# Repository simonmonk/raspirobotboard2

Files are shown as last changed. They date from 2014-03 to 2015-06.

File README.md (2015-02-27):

Source code for use with the RaspiRobot Board V2.

**Note that if you are looking for version 1 of this board, please see:**

https://github.com/simonmonk/raspirobotboard

***Both version 1 and version 2 of the RasPiRobot Board work just fine with the new Raspberry Pi2 and the Model B+***

# Support
If you need any help with the software or board please contact linda@monkmakes.com or leave a comment on monkmakes.com

# Introduction

Version 2 of the RaspiRobot Board (RRB2) has learnt by the feedback from version 1 and it is a great improvement. 

RRBv2

The main features of version 2 are listed below. Changes from version 1 are highlighted in bold:
+ **Supplied fully assembled - no soldering**
+ Bi-directional control of two motors
+ **Variable (PWM) power control**. This allows you to both control the speed of the motors independently. 
+ **Supplies the Raspberry Pi with upto 2A using a switch mode power supply - run a fully loaded Pi and the Robot from 6 x AA batteries**
+ **Rangefinder header socket directly compatible with cheap HC-SR-04 ultrasonic range finders. Just plug them in directly**
+ **5V I2C header, pin compatible with Adafruit displays**
+ Two buffered open collector outputs
+ Two LEDs
+ Two switch inputs
+ Screw terminals for motors and battery

RRBv2

# How it Works

The diagram below shows how an RRB2 board is used. The RRB2 is powered from a battery pack that needs to be between 6 and 12V DC. Although using 4 x AA batteries can in theory provide 6V, actually the battery voltage will usually quickly fall below that, so it it better to use at least 6 x AA batteries, either rechargeable or regular heavy duty batteries. A 7.2V LiPo battery pack will also work just fine.

RRBv2

Note that you don't need a separate power supply for the Raspberry Pi. The RRB2 will provide 5V at 2A with ease to the Raspberry Pi, and motors. 

Note that 6V motor will usually work just fine at 5V.

# Installing the Python Libraries

On your Raspberry Pi, issue the following commands in a Terminal window:

```
$ wget https://github.com/simonmonk/raspirobotboard2/raw/master/python/dist/rrb2-1.1.tar.gz
$ tar -xzf rrb2-1.1.tar.gz
$ cd rrb2-1.1
$ sudo python setup.py install
```

Attach the RRB2 to your Raspberry Pi. You do not need to attach batteries, motors or anything else to the RRB2 just yet. For now you can just power it through the Pi's normal USB power connector.

Lets run some tests from the Python Console now that everything is installed. We can experiment with the RaspiRobot Board v2, even without any motors 

Open a Python console (Python2 not 3) by typing the following into a Terminal window:
`$ sudo python`

Then, within the python console, type the following, one line at a time:

```
from rrb2 import *
rr = RRB2()
rr.set_led1(1)
rr.set_led1(0)
rr.set_led2(1)
rr.set_led2(0)
rr.sw1_closed()
```

The last step should display the answer "False" because no switch is attached.

If you prefer, you can use True and False in place of 1 and 0 in the examples above.

# Connect a Battery and Motors

The quickest way to use the RRB2 as a roving robot is to buy a robot chassis such as the Magician Chassis (available from many sources) or similar low-cost robot chassis kits from eBay. These kits come as a laser cut body, a pair of gearmotors, often a battery box and nuts and bolts to fix it all together.

Here is one such chassis. The first step is to bolt this all together. Note that these are usually supplied with a 4 x AA battery box. You will need to swap this for a similar 6 x AA battery box or a 7.2V LiPo battery pack. Rechargeable batteries are a good idea when driving motors.

Chassis

Once the chassis is built, use some of the bolts suppled to fix the Raspberry Pi on the chassis and then attach the RRB2 onto the GPIO connector. Make sure its the right way arround, and that all the pins meet up with the socket.

The leads from the motors will thread up through the chassis and each pair of leads should go to one of the two screw terminals labelled L and R for (left and right). If you put the leads in the wrong way around, the direction of the motor will be opposite to that expected, so just swap them over if this happens.

Motor wiring

Next, make sure that your Raspberry Pi's USB power lead is unplugged. From now on we are going to power it from batteries.

**WARNING: Never power the Raspberry Pi from both batteries and the USB power connector. One or other, but NOT both.**

It is a good idea to leave the wheels off the robot chassis for now so that it does not unexpectedly drive itself off your table. One or both of the motors may spin as the Raspberry Pi starts up.

Wire the battery pack into the third pair of screw terminals. +V towards the outside of the board. The Raspberry Pi's power light should light up and it will start to boot. LED1 and LED2 on the RRB2 will also light up.

Having your Pi set up for WiFi will allow you to connect to it wirelessly [over SSH](http://learn.adafruit.com/adafruits-raspberry-pi-lesson-6-using-ssh/overview). So, you may want to plug in a USB WiFi dongle.

# API Reference

## General
The library implements a class called RRB2. This is only available for Python 2 and any Python programs that you write that use the libaray must be run as a super user. I.e.

`sudo python myProgram.py'

To import the library and create an instance of the class, put this at the top of your Python program.

```
from rrb2 import *
rr = RRB2()
```

If you have an older revision 1 Raspberry Pi, then you need to do this instead:

```
from rrb2 import *
rr = RRB2(revision=1)
```

The rest is pretty straightforward, there are just a load of useful methods on the class that you can use.

## LEDs

There are two LEDs built-in to the RaspiRobotBoard, called LED1 and LED2. Both of these can be turned on and off using the following methods:

To turn LED1 on just do:

`rr.set_led1(1)`

To turn it off again do:

`rr.set_led1(0)`

To control LED2 just do the same thing but using setLED2.

## Switch Inputs

The sw1_closed() and sw2_closed() functions return true if the contacts for that switch are closed. By default, the switches are open. You can test out closing the switch by shorting the two contacts with a screwdriver.

The following test program will show you the state of each of the switch contacts.

```
from rrb2 import *

rr = RRB2()

while True:
    print("SW1=" + str(rr.sw1_closed()) + " SW2=" + str(rr.sw2_closed()))
    raw_input("check again")
```

## Open Collector Outputs

The RaspiRobotBoard has two low-power open collector outputs. These can each source up to 25mA and so are suitable for driving LEDs with series resistors. They can also be used to drive transistors and other external electronics. They are buffered and therefore protect the Raspberry Pi' s processor.

To turn the Open Collector OC1 output on just do:

`rr.set_oc1(1)`

To turn it off again do: 

`rr.set_oc1(0)`

To control OC2, substitute oc2 in place of oc1 in the examples above

## Motor (High Level Interface)

There are two levels of command for controlling the motors. There is a high level interface that assumes that the motors are connected to wheels on a rover. These commands are forward, reverse, left, right and stop.

`rr.forward()`

... will start both motors running in the same direction to move the robot rover forwards. They will continue in this direction until another command is issued.

If you want to move forward for a certain amount of time, you can specify a number of seconds as an optional first argument. If you supply a second parameter between 0 and 1 this will control the speed of the motor. This is set to 0.5 as a defaut. If you want the motors to run indefinately, but also want to control the speed, then use 0 as the first patrameter.

Some examples:

```
rr.forward()       # forward half speed indefinately
rr.forward(5)      # forward for 5 seconds at half speed
rr.forward(5, 1)   # forward for 5 seconds at full speed
```

The commands left, right and reverse all work in the same way.

The stop command stops all the motors.

## Motor (Low Level Interface)

The low level interface is intended for control of the motors directly. It allows you to control the speed of each motor and its direction independently.

The method for this (set_motors) takes four arguments: the left speed, left motor direction, right spped and direction.

So to set both motors going forward at full speed, you would just use the following:

`rr.set_motors(1, 0, 1, 0)`

.. and half speed would be:

`rr.set_motors(0.5, 0, 0.5, 0)`

to send the motors both at half speed in opposite directions is:

`rr.set_motors(0.5, 1, 0.5, 0)`

## Range Finder

If you fit the RRB2 with an SR-04 ultrasonic rangefinder, then you can use the following call to measure the distance to the enarest obstacle in cm.

`rr.get_distance()`

## Hardware

The RRB2 uses the following pins:

    LEFT_GO_PIN = 17
    LEFT_DIR_PIN = 4
    RIGHT_GO_PIN = 10
    RIGHT_DIR_PIN = 25   
    SW1_PIN = 11
    SW2_PIN = 9
    LED1_PIN = 7
    LED2_PIN = 8
    OC1_PIN = 22
    OC2_PIN = 27
    OC2_PIN_R1 = 21 (rev 1) or 27 rev 2
    TRIGGER_PIN = 18
    ECHO_PIN = 23

The LEDs and OC outputs are buffered. The switch inputs are not.

You can find the EAGLE design files in the "hardware" section of tis repo.

# Using I2C Displays

The I2C socket is pin compatible with these Adafruit displays: 
+ [4 Digit 7-segment display (red)](http://www.adafruit.com/products/878)
+ [Mini 8x8 LED Matrix (red)](http://www.adafruit.com/products/870)
+ [Bi-color 8x8 LED Matrix (red)](http://www.adafruit.com/products/902)

To use these you will need to download Adafruit's Python library for the Pi from [here](http://learn.adafruit.com/matrix-7-segment-led-backpack-with-the-raspberry-pi/overview).

Make sure that you plug the display in the right way around. The socket pins are labelled on the RRB2, make sure they match up with the labels on the display. You can use male to female jumper wires if you wish to put the display further away or its too big.

# Example Projects

Have a look in the "examples" folder of this library for some examples using the RRB2.

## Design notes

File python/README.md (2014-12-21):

raspirobotboard 2
=================

Source for the RaspiRobotBoard Python library.

For full instructions for installation and use, see:

https://github.com/simonmonk/raspirobotboard2

for Version 1 (through hole kit) of the RaspiRobotBoard, see: https://github.com/simonmonk/raspirobotboard/wiki

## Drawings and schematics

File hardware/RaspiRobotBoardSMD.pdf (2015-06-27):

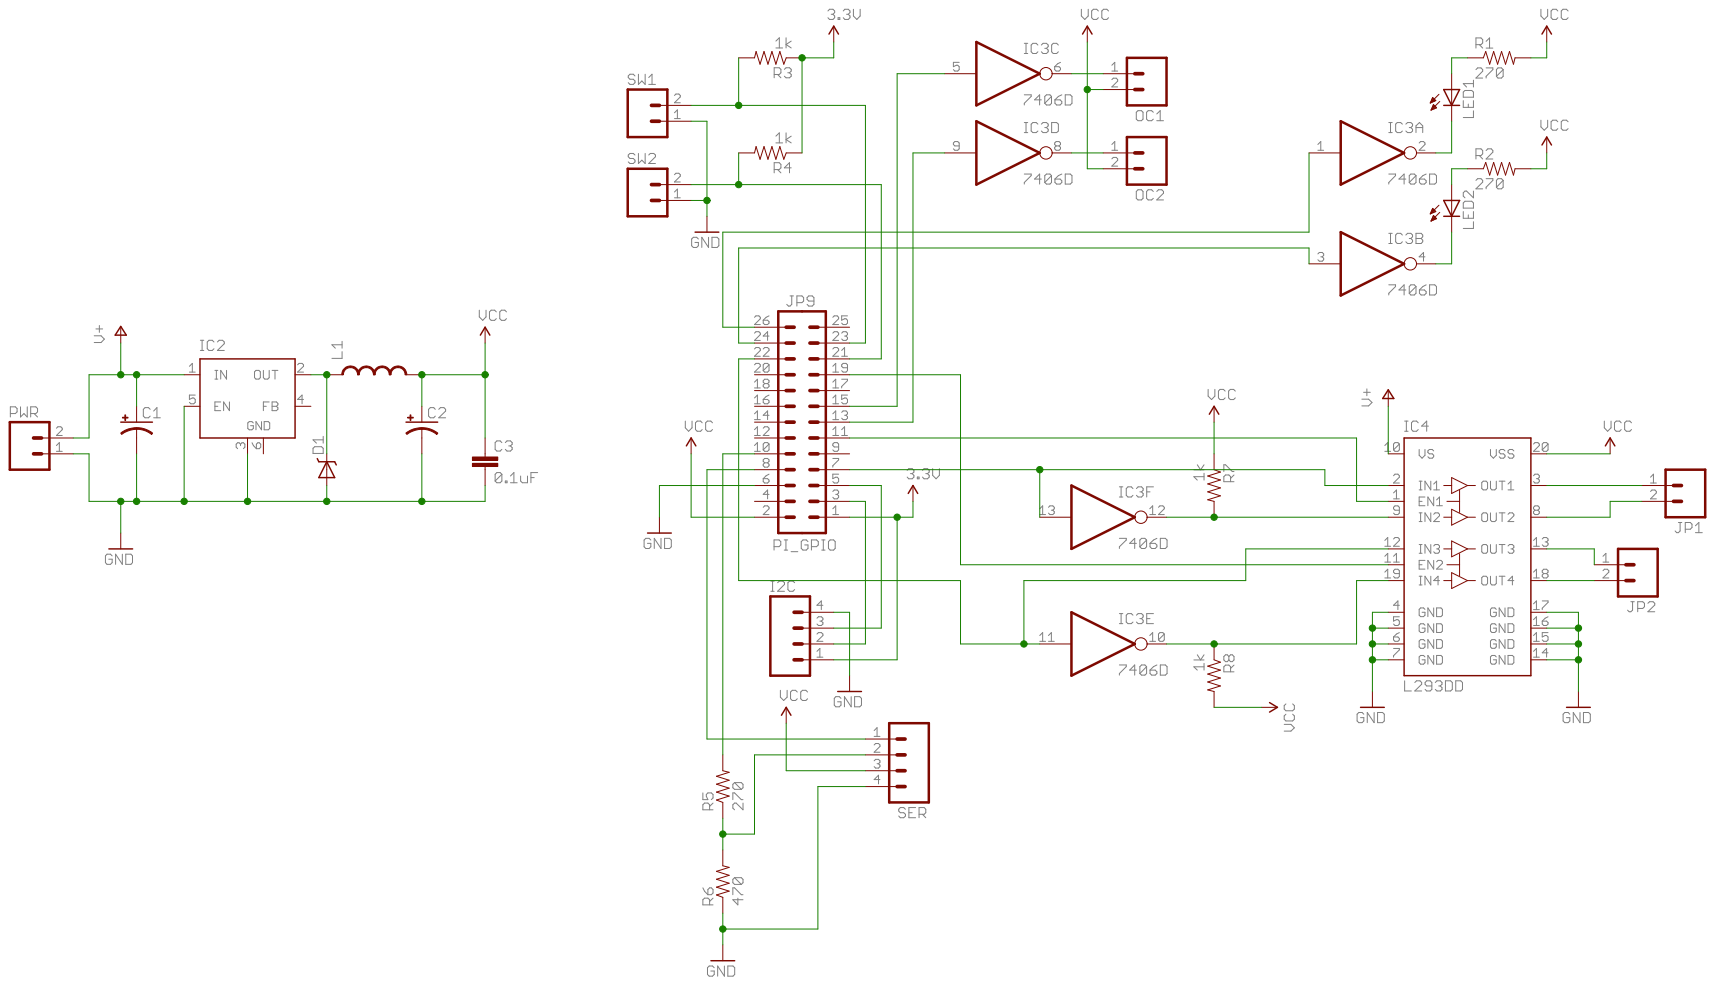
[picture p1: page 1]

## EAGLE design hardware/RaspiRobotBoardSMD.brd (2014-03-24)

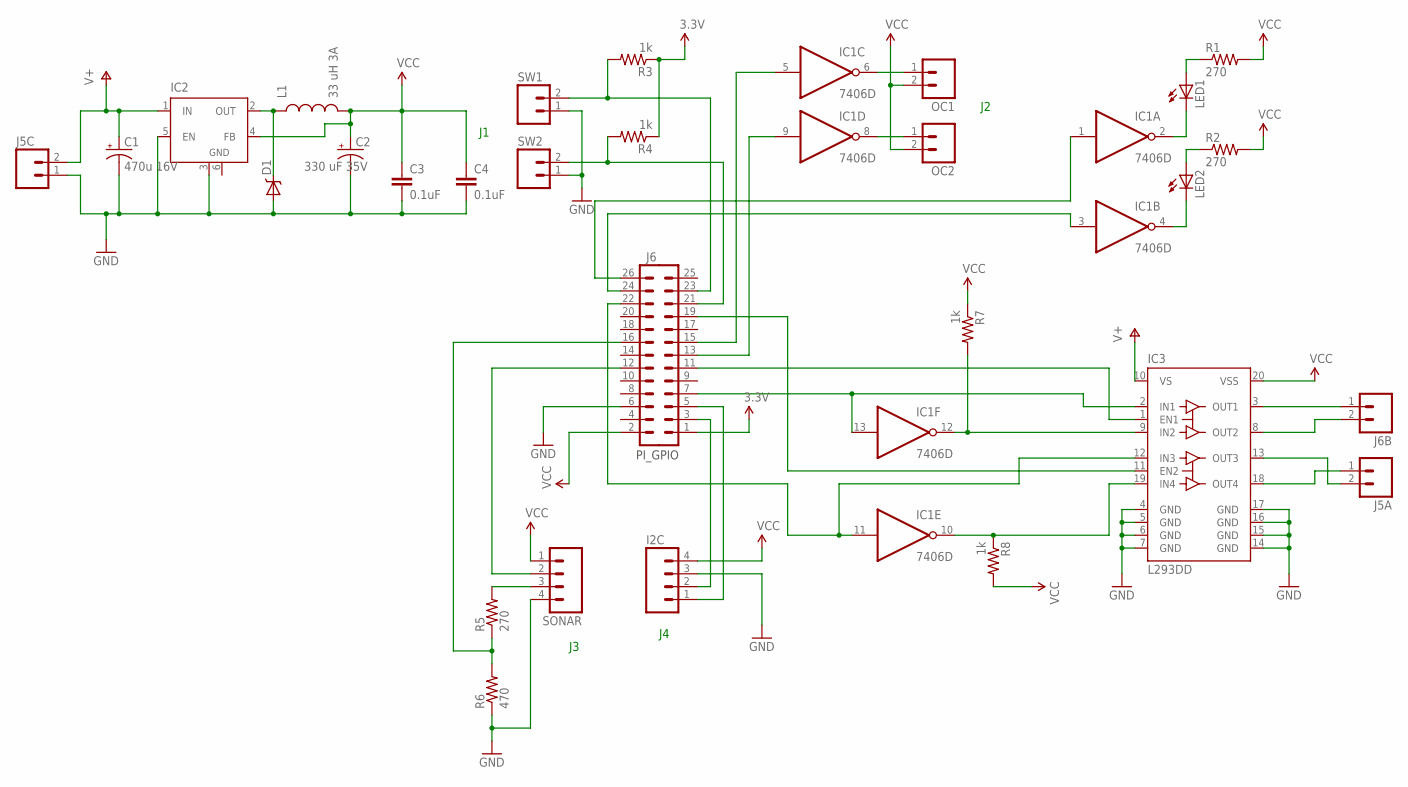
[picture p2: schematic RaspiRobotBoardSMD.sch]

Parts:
C1: 470u 16V; PANASONIC_E
C2: 330 uF 35V; PANASONIC_G
C3, C4: 0.1uF; 0805
D1: B340A; SMA-DIODE
I2C: M04PTH; 1X04
IC1: 7406D; SO14
IC2: LM2596S; TO263-5
IC3: L293DD; SO20
J5A, J5C, J6B: M023.5MM_LOCK; SCREWTERMINAL-3.5MM-2_LOCK
J6: M13X22X13; 2X13
L1: 33 uH 3A; CDRH125
LED1, LED2: LEDSMT1206; 1206
OC1, OC2: M02PTH; 1X02
R1, R2, R5: 270; 0805
R3, R4, R7, R8: 1k; 0805
R6: 470; 0805
SONAR: M04PTH; 1X04
SW1, SW2: M02PTH; 1X02

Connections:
3.3V: J6.1, R3.1, R4.1
GND: C1.-, C2.-, C3.2, C4.2, D1.A, I2C.3, IC1.7 (GND), IC2.3 (GND), IC2.5 (EN), IC2.6 (GND), IC3.4 (GND), IC3.5 (GND), IC3.6 (GND), IC3.7 (GND), IC3.14 (GND), IC3.15 (GND), IC3.16 (GND), IC3.17 (GND), J5C.1, J6.6, R6.1, SONAR.4, SW1.1, SW2.1
unnamed: D1.C, IC2.2 (OUT), L1.1
unnamed: IC3.3 (OUT1), J6B.1
unnamed: IC3.8 (OUT2), J6B.2
unnamed: IC3.18 (OUT4), J5A.1
unnamed: IC1.13 (I), IC3.2 (IN1), J6.7
unnamed: IC1.12 (O), IC3.9 (IN2), R7.2
unnamed: IC1.10 (O), IC3.19 (IN4), R8.1
unnamed: IC1.11 (I), IC3.12 (IN3), J6.22
unnamed: LED1.A, R1.1
unnamed: LED2.A, R2.1
unnamed: IC1.2 (O), LED1.C
unnamed: IC1.4 (O), LED2.C
unnamed: IC1.6 (O), OC1.1
unnamed: IC1.8 (O), OC2.1
unnamed: J6.23, R3.2, SW1.2
unnamed: J6.21, R4.2, SW2.2
unnamed: IC1.3 (I), J6.24
unnamed: J6.16, R5.1, R6.2
unnamed: J6.12, SONAR.2
unnamed: R5.2, SONAR.3
unnamed: IC1.1 (I), J6.26
unnamed: IC3.1 (EN1), J6.11
unnamed: IC3.11 (EN2), J6.19
unnamed: IC1.9 (I), J6.13
unnamed: IC1.5 (I), J6.15
unnamed: I2C.2, J6.3
unnamed: I2C.1, J6.5
unnamed: IC3.13 (OUT3), J5A.2
V+: C1.+, IC2.1 (IN), IC3.10 (VS), J5C.2
VCC: C2.+, C3.1, C4.1, I2C.4, IC1.14 (VCC), IC2.4 (FB), IC3.20 (VSS), J6.2, L1.2, OC1.2, OC2.2, R1.2, R2.2, R7.1, R8.2, SONAR.1

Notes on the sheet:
PI_GPIO

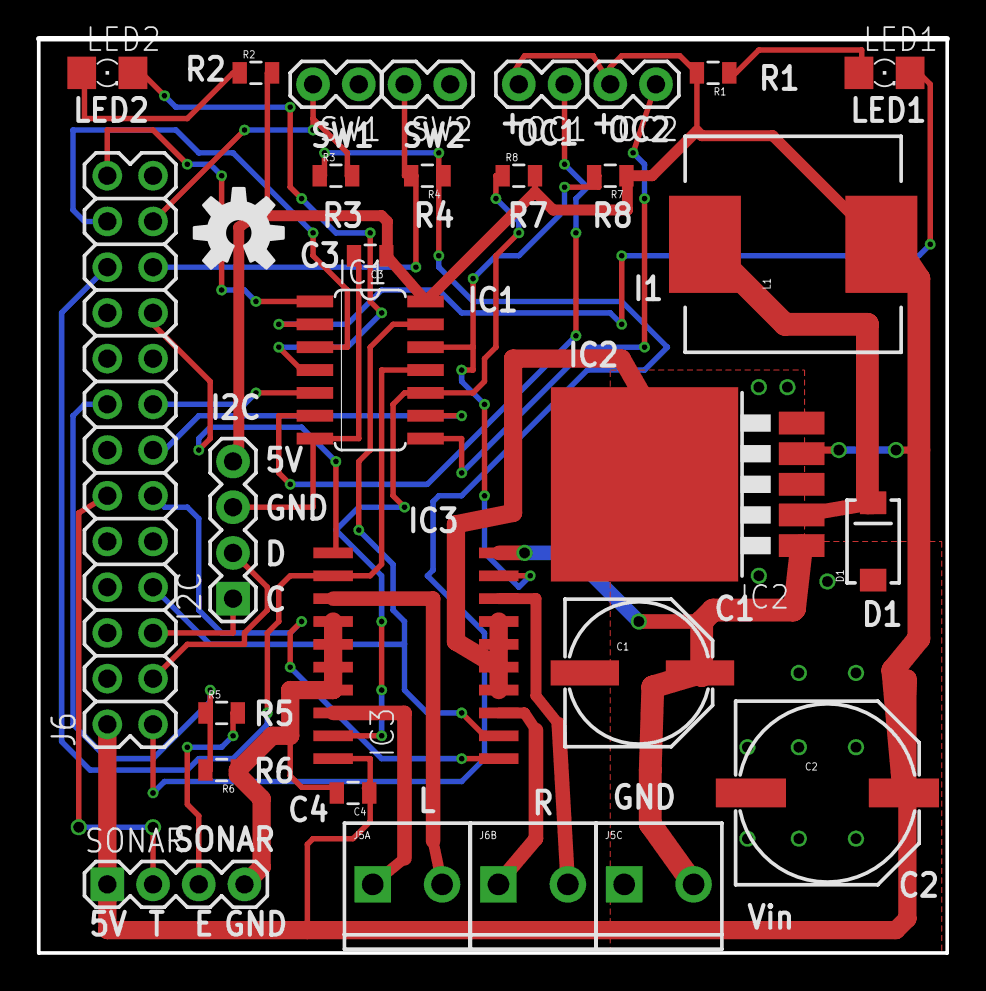
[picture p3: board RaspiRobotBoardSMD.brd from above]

Board: 2 copper layers, 50.5 x 50.8 mm, 30 parts (0 on the bottom side), 32 nets.

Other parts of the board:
U$1: OSHW-LOGO-M

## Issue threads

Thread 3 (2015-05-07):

12V 4.2A input?

HsienYu, 2015-05-07:
Hi,
I am wondering is the input voltage same as v1 (5v ~ 12`v)?

thanks!!

simonmonk, 2015-05-07:
The RRB2 will cope with up to 15V in.

However, be aware that unlike the RRB1, the RRB2 supplies 5V regulated power to the motors, rather than the input voltage.

Si.

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

--
Simon Monk. http://www.simonmonk.org

HsienYu, 2015-05-07:
Cool, thanks!
I have other question, my pi b 2 always reboot when I use rrrb2.
It often happens when I except command via ssh with wifi dongle.

simonmonk, 2015-05-07:
What battery pack are you using?

The problem is that the battery voltage will drop, when say motors start up and if the voltage drops too low it causes the Pi to restart. Using something like a 7.4V LiPo battery or 6 x AA battery pack should prevent this.

Si.

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

--
Simon Monk. http://www.simonmonk.org

--
Simon Monk. http://www.simonmonk.org

HsienYu, 2015-05-08:
I am using 6 x AA and 12v dc 4.2a adapter for testing, but with 6 xAA the reboot issue still happenes when I execute command. um... kind of wired. But thanks a lot!! I will check all the details and update soon!

HsienYu, 2015-05-09:
Hi Simon,
I did the setup with 7.4V LiPo battery, but it seem to be nothing changed.
My pi also often reboot when my motor started.

Do you know some way to avoid this kind of things happen?

Thank you very much!!

simonmonk, 2015-05-09:
What kind of motors are you using?

One trick is to put a high value capacitor say 1000uF 25V in the Vin screw terminals (longer lead of capacitor to +V).

Another trick is to start the motor at slow speed first then increase speed after say 1/10 second.

Si.

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

--
Simon Monk. http://www.simonmonk.org

HsienYu, 2015-05-10:
I am using regular 7.2 dv motor. I did try increasing speed, it's fine now.
Thank you very much and appreciate that!!

Have a good day!

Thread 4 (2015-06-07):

How to connect additional GPIO devices?

cudmore, 2015-06-07:
It is really nice that the board comes pre-soldered.

Is there any way to attach additional input/output devices to the unused GPIO pins of the raspberry? It seems all the pins on the Pi are 'capped off' because of the 'pre-soldered' connector.

Can you ship the controller with everyhting soldered except the GPIO connector? I could just solder an extra tall male to female connector (tall male running through motor controller and sticking out the top, female inserted into Pi GPIO below.

Is there some sort of 'T' connector one could put between the Pi and the motor controller? To give access to the pins.

I am always connecting junk to my Pi GPIO. To start, I would like to connect 2 servos for pan/tilt of a Rapsberry Pi Camera.

Thanks

cudmore, 2015-06-07:
i just found this tutorial where the motor board has extra tall headers. Is this how it is shipped? I am about to buy it.

https://learn.adafruit.com/controlling-motors-using-the-raspberry-pi-and-raspirobot-board-v2?view=all

ismailuddin, 2015-06-07:
The board is shipped with a tall header which you can (physically atleast) connect other pins on to it. There's table in the README file listing which pins are used by this board, so if I'm not mistaken, any pin not being used should be accessible through the header on the board for your own use..?

cudmore, 2015-06-07:
Thanks so much #ismailuddin. I will order one now and start my first robot!

Just for reference, I cross posted here:
   https://forums.adafruit.com/viewtopic.php?f=50&t=64168

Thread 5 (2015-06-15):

Raspberry PI rebooting when executing rr.forward

Nick-B31, 2015-06-15:
When I try to execute the below the Raspberry Pi crashes.  I have installed the appropriate libraries and followed the readme.

>from rrb2 import *
>rr = RRB2()
>rr.forward()

Using a Rapsberry Pi Model B Revision 2.0 (512MB) with an Edimax EW-7811Un USB Wi-Fi adapter with the RaspiRobot v2 board and two 6v DC motors.

I am able to control the LEDs with these commands:

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

Thanks in advance.

simonmonk, 2015-06-15:
What are you using for a battery pack?

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

--
Simon Monk. http://www.simonmonk.org

Nick-B31, 2015-06-15:
Thank you very much for the quick response! I am powering it from the Raspberry Pi USB power. Nothing connected to the power terminals on the RaspiRobot Board.

simonmonk, 2015-06-15:
OK, that's your problem. You need a battery pack or 9-12V power supply connected the the RRBv2 screw terminals.

Si.

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

--
Simon Monk. http://www.simonmonk.org

Nick-B31, 2015-06-15:
I had a spare PSU available. I've used one of the 12v power lines and GND on it.

I am able to get both motors to "hum" with this command now instead of crashing:

>rr.set_motors(0.5, 1, 0.5, 0)

Running the below script I am able to get the motors to hum at the "Is one motor going forwards at half speed?" question and the motors for a split second will go in the direction they are supposed to at what seems like a reasonable speed. I have verified they move freely otherwise.

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
 >   answer = raw_input(question)
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

Results:

1. Are Both motors going forwards? - Nothing
2. Is one motor going forwards at half speed? - Humming and Left Motor moves slight when moving on to next command/question
3. Are both motors going backwards? - Nothing

Thanks again

Nick-B31, 2015-06-16:
The problem of getting the motors to turn/stop humming still persists after moving to 9v wall wart. If you'd like to treat this as a separate problem I am happy to mark this issue closed as switching over to either 9v or 12v PSU solved the problem of the Rpi crashing.

Closed 2015-06-16.

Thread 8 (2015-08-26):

Add wheel encoders to raspirobot

actkk2000, 2015-08-26:
Hi, I would like to now if it would be possible to add a python code to read data from wheel encoders.
This would be in order allow to drive the robot in a straight line.
Currently I am using pwm to balance speed of motors in manually way, but it is not very precise.
I have seen your robot kit comes with encoders, although I have a similar kit without encoders but with sproket disks and I am planning to buy this encoder, supposedly designed for that:
https://www.sparkfun.com/products/12617
Any help will be much appreciated.
Thank you.

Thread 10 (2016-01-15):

Getting only 3,5v for the motors

Tapsa84, 2016-01-15:
Hi,

I am driving a 6v motor without pwm, and getting only 3,5v to the motor. What could the issue be?

Cheers,
Tapsa

simonmonk, 2016-01-20:
Hi,

The RRB2 supplies motor power from the regulated 5V supply and by the time the motor controller has done its job, 3.5 to 4V is to be expected.

Simon.

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

--
Simon Monk. http://www.simonmonk.org

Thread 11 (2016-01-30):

wireless connection

dwphoto, 2016-01-30:
When using the raspirobot board, the rpi loses wireless connection if motors run for an extended time.  Otherwise wireless is solid. Any ideas on this?  I figure some sort of rfi.

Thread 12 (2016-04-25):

Is it allright to connect a 10x AA batteries to the rrb2?

shakeel-khan8879, 2016-04-25:
Hi there,
I have been working on a robotics project that is such that I think would make a power hungry robot. What I have attached to my robot is:
A wi-fi dongle
A Raspberry pi Camera
Two motors for my chassis (I'm using the same one mentioned in the README file)
An arduino Uno which has a accelerometer,  and two servos attached ( this has its own 4x AA power supply)
Two LED’S on the rrb2

So will a 8x AA battery holder cut it or will I need the hefty 10x AA battery holder?
Thanks,
Shak

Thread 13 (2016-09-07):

Issue with 10V power supply

blm08, 2016-09-07:
Hi !

When I power the raspirobot with a 10V battery, the Raspberry Pi doesn't boot and LEDs (both from raspirobot and the green one from the Pi) start to flash approximatively every second.

Can you help me ? Thanks !

simonmonk, 2016-09-08:
It sounds like the battery voltage is dropping as soon as its loaded by the
Pi. What kind of battery are you using?

Si.

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

--
--
http://simonmonk.org
@simonmonk2

blm08, 2016-09-13:
Well, I'm using two USB batteries with 5V 1A each in series, which results theorically in a 10V 1A power supply. Is there any way to fix that voltage drop ?

simonmonk, 2016-09-13:
If you are using USB LiPo battery backup devices, then the problem is
likely to current limiting at 0.5A. As soon as the motors try and draw
more, both batteries will drop the voltage to protect themselves.

Have you tried using one battery to power the PI and a separate one to
power the motors? Note the RRB3 library has the option to specify the
battery and motor voltages.

Si.

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

--
--
http://simonmonk.org
@simonmonk2

blm08, 2016-09-13:
It is actually Li-Ion batteries, they are able to provide more than 0.5A because it works well with only one of them (but the motors don't get enough power).

Using one battery to power the Pi and another to power the motors seems interesting though. Can I still do it with RRB2 ? If so, how can I do that concretly ?

Thanks again for your help, it would be really great if that worked !

blm08, 2016-09-25:
Any news about it ?

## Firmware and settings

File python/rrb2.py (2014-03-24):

#rrb2.py Library

import RPi.GPIO as GPIO
import time

class RRB2:
	
    LEFT_GO_PIN = 17
    LEFT_DIR_PIN = 4
    RIGHT_GO_PIN = 10
    RIGHT_DIR_PIN = 25   
    SW1_PIN = 11
    SW2_PIN = 9
    LED1_PIN = 7
    LED2_PIN = 8
    OC1_PIN = 22
    OC2_PIN = 27
    OC2_PIN_R1 = 21
    OC2_PIN_R2 = 27
    TRIGGER_PIN = 18
    ECHO_PIN = 23
    left_pwm = 0
    right_pwm = 0

    def __init__(self, revision=2):
        GPIO.setmode(GPIO.BCM)
        GPIO.setwarnings(False)

        GPIO.setup(self.LEFT_GO_PIN, GPIO.OUT)
        self.left_pwm = GPIO.PWM(self.LEFT_GO_PIN, 500)
        self.left_pwm.start(0)
        GPIO.setup(self.LEFT_DIR_PIN, GPIO.OUT)
        GPIO.setup(self.RIGHT_GO_PIN, GPIO.OUT)
        self.right_pwm = GPIO.PWM(self.RIGHT_GO_PIN, 500)
        self.right_pwm.start(0)
        GPIO.setup(self.RIGHT_DIR_PIN, GPIO.OUT)

        GPIO.setup(self.LED1_PIN, GPIO.OUT)
        GPIO.setup(self.LED2_PIN, GPIO.OUT)

        GPIO.setup(self.OC1_PIN, GPIO.OUT)
        if revision == 1:
            self.OC2_PIN = self.OC2_PIN_R1
        else:
            self.OC2_PIN = self.OC2_PIN_R2

        GPIO.setup(self.OC2_PIN_R2, GPIO.OUT)

        GPIO.setup(self.SW1_PIN, GPIO.IN)
        GPIO.setup(self.SW2_PIN, GPIO.IN)
        GPIO.setup(self.TRIGGER_PIN, GPIO.OUT)
        GPIO.setup(self.ECHO_PIN, GPIO.IN)



    def set_motors(self, left_go, left_dir, right_go, right_dir):
        self.left_pwm.ChangeDutyCycle(left_go * 100)
        GPIO.output(self.LEFT_DIR_PIN, left_dir)
        self.right_pwm.ChangeDutyCycle(right_go * 100)
        GPIO.output(self.RIGHT_DIR_PIN, right_dir)

    def forward(self, seconds=0, speed=0.5):
        self.set_motors(speed, 0, speed, 0)
        if seconds > 0:
            time.sleep(seconds)
            self.stop()

    def stop(self):
        self.set_motors(0, 0, 0, 0)
 
    def reverse(self, seconds=0, speed=0.5):
        self.set_motors(speed, 1, speed, 1)
        if seconds > 0:
            time.sleep(seconds)
            self.stop()
    
    def left(self, seconds=0, speed=0.5):
        self.set_motors(speed, 0, speed, 1)
        if seconds > 0:
            time.sleep(seconds)
            self.stop()

    def right(self, seconds=0, speed=0.5):
        self.set_motors(speed, 1, speed, 0)
        if seconds > 0:
            time.sleep(seconds)
            self.stop()

    def sw1_closed(self):
        return not GPIO.input(self.SW1_PIN)

    def sw2_closed(self):
        return not GPIO.input(self.SW2_PIN)

    def set_led1(self, state):
        GPIO.output(self.LED1_PIN, state)

    def set_led2(self, state):
        GPIO.output(self.LED2_PIN, state)

    def set_oc1(self, state):
        GPIO.output(self.OC1_PIN, state)

    def set_oc2(self, state):
        GPIO.output(self.OC2_PIN, state)    

    def _send_trigger_pulse(self):
        GPIO.output(self.TRIGGER_PIN, True)
        time.sleep(0.0001)
        GPIO.output(self.TRIGGER_PIN, False)

    def _wait_for_echo(self, value, timeout):
        count = timeout
        while GPIO.input(self.ECHO_PIN) != value and count > 0:
            count = count - 1

    def get_distance(self):
        self._send_trigger_pulse()
        self._wait_for_echo(True, 10000)
        start = time.time()
        self._wait_for_echo(False, 10000)
        finish = time.time()
        pulse_len = finish - start
        distance_cm = pulse_len / 0.000058
        return distance_cm

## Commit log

2014-02-13 fixes for test prog
    [rrb2.py]
2014-02-13 added pwm to motors
2014-03-24 added EAGLE files
    [RaspiRobotBoardSMD.brd, RaspiRobotBoardSMD.sch]
2015-06-27 added schematic

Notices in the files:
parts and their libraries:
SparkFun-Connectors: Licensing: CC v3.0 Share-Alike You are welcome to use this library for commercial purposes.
